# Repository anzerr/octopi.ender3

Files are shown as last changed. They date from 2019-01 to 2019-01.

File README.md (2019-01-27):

### `Intro`
Wanted to use Octoprint on a raspberry pi zero w because of its small footprint and low power usage.

Warning: The zero w will not work with a camera the CPU usage is hight negatively impacting printing results.

### `Bill of materials`
- 1 x Boost Buck Converter XL6009
- 2 x T Block Square nuts 2020 m3 or [printed version](https://www.thingiverse.com/thing:3050607)
- 1 x raspberry pi zero w
- 1 x 16gb sd card
- 2 x xt60 plug pair
- 30cm+ 14awg silicone cable
- 1 x 1k ohm resistor
- 2 x M3 Brass knurled female thread insert
- 4 x 19mm M3 screw
- 1 x 5mm M3 screw
- 1 x M3 nut
- 2 x zip ties
- Heat shrink tubing
- Hot glue or double sided tape (for the xt60 y connector)
- 1 x usb mini B to usb

### `Setup Pi`
- [Download the os](https://octoprint.org/download/)
- [Use etch flash the image onto a sd card](https://github.com/balena-io/etcher)
- Edit the octopi-wpa-supplicant.txt with your wifi credenciales.
- Connect to the octopi and finish the setup process.

### `Prints`
You can print most of these without supports. The models can be found in "./models" the source files are there with the stl. The models where made with sketchup

- 1 x [xt60_y_connector (no support)](https://github.com/anzerr/octopi.ender3/blob/master/models/stl/xt60_y_connector.stl)
- 1 x [pi_base (no support)](https://github.com/anzerr/octopi.ender3/blob/master/models/stl/pi_base.stl)
- 1 x [boost_base (no support)](https://github.com/anzerr/octopi.ender3/blob/master/models/stl/boost_base.stl)
- 1 x [case (touching buildplate support)](https://github.com/anzerr/octopi.ender3/blob/master/models/stl/case.stl)
- 2 x [spacer_pi (touching buildplate support)](https://github.com/anzerr/octopi.ender3/blob/master/models/stl/spacer_pi.stl)
- 1 x [spacer (no support)](https://github.com/anzerr/octopi.ender3/blob/master/models/stl/spacer.stl)

The only clean up needed should be drilling the holes so the screw can move freely. Add the two brass inserts to the pi_base and the parts will be ready to be assembled.

### `Wiring`
The pi pads with labels
<div style="text-align:center">
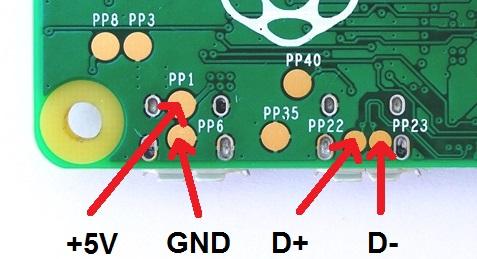
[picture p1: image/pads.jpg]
	
</div>

- Creating the xt60 Y connector.
- Use the left over male connector with the 14awg cable to create the wiring to the buck converter.
- Set the buck converter to a little under 5v.
- Wire power to the pads under the raspberry pi.
- Cut the male usb mini b cable to length and strip.
- add the 1k ohm resistor between the +5v on the pi and the red wire from the usb mini.
- wire the rest, black to gnd, green to d+ and white to d-. (on my usb mini cable I had to swap d+ and d-)

### `Images`
<div style="text-align:center">
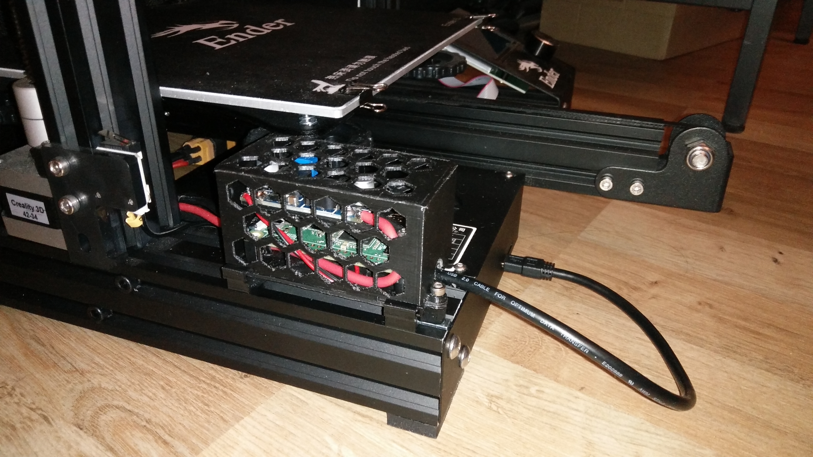
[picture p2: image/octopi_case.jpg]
	
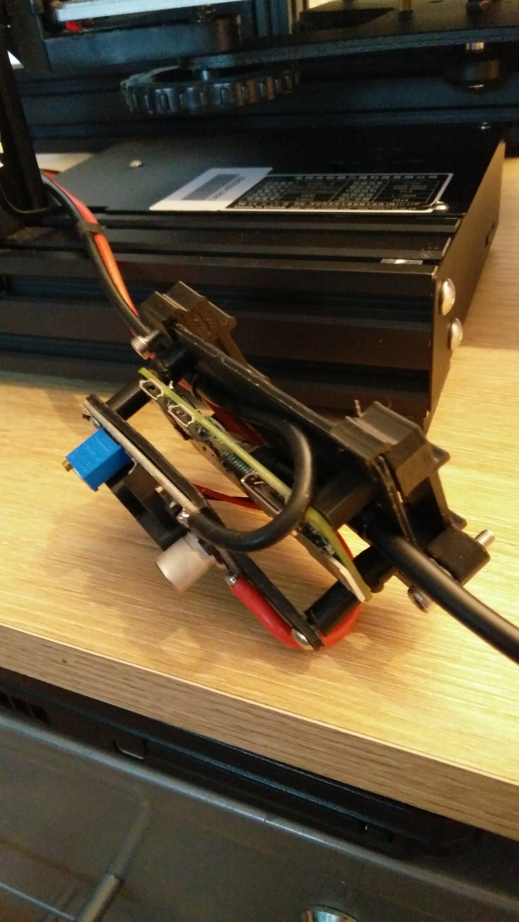
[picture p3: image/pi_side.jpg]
	
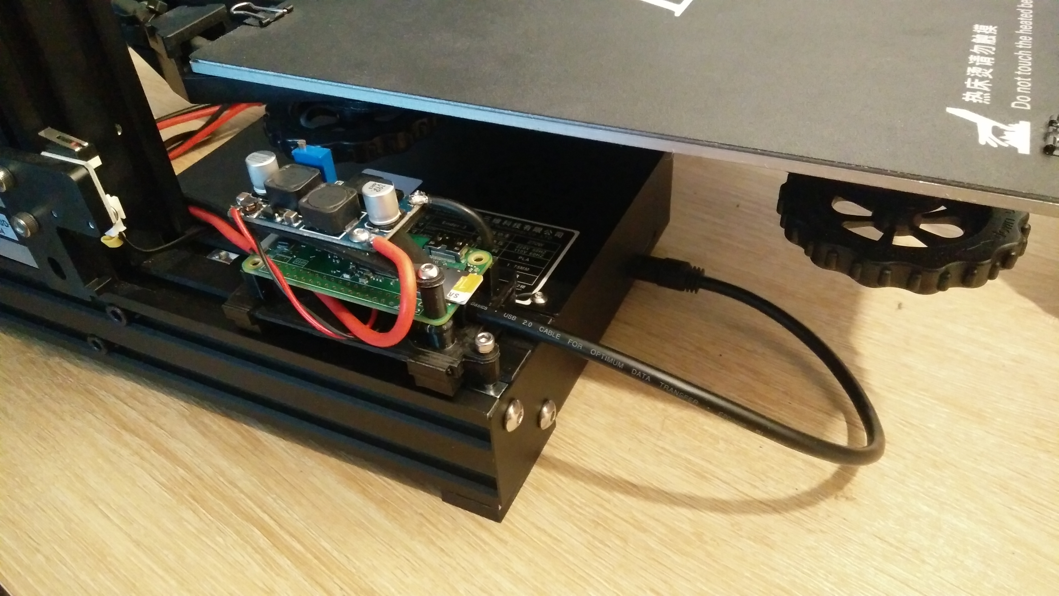
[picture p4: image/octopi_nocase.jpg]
	
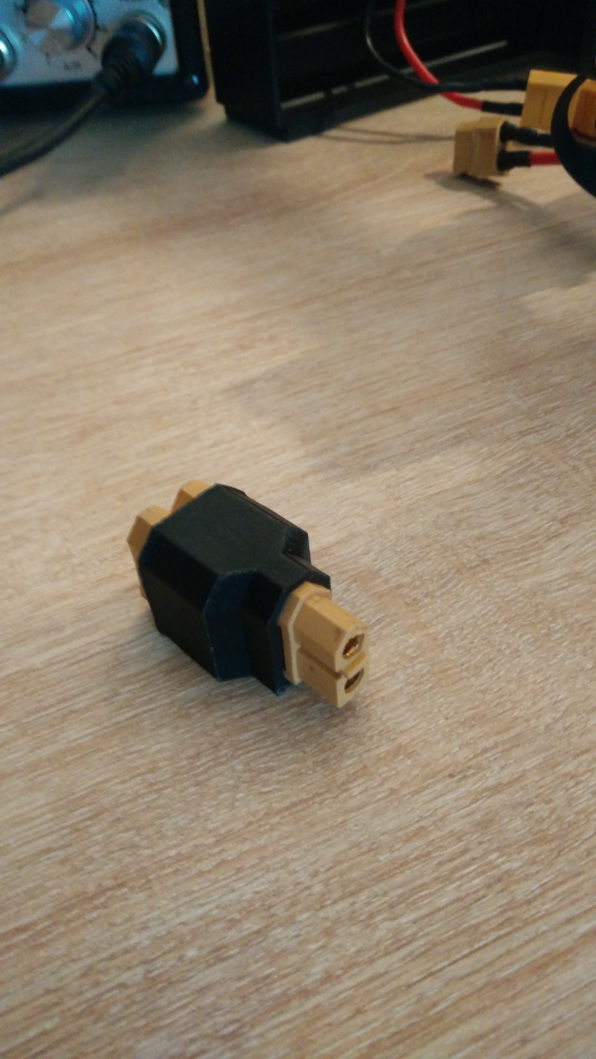
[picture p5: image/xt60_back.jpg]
	
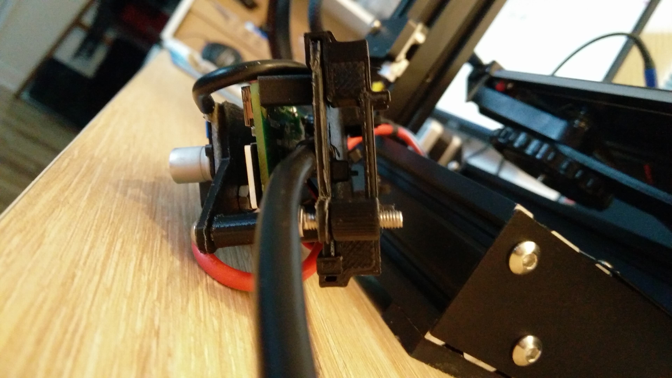
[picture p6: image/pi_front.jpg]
	
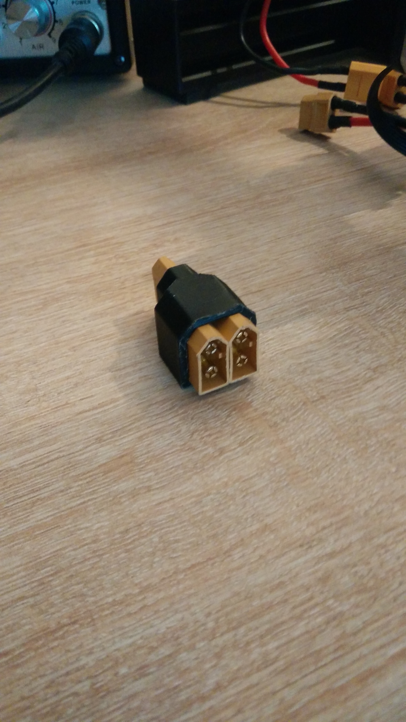
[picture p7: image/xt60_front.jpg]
	
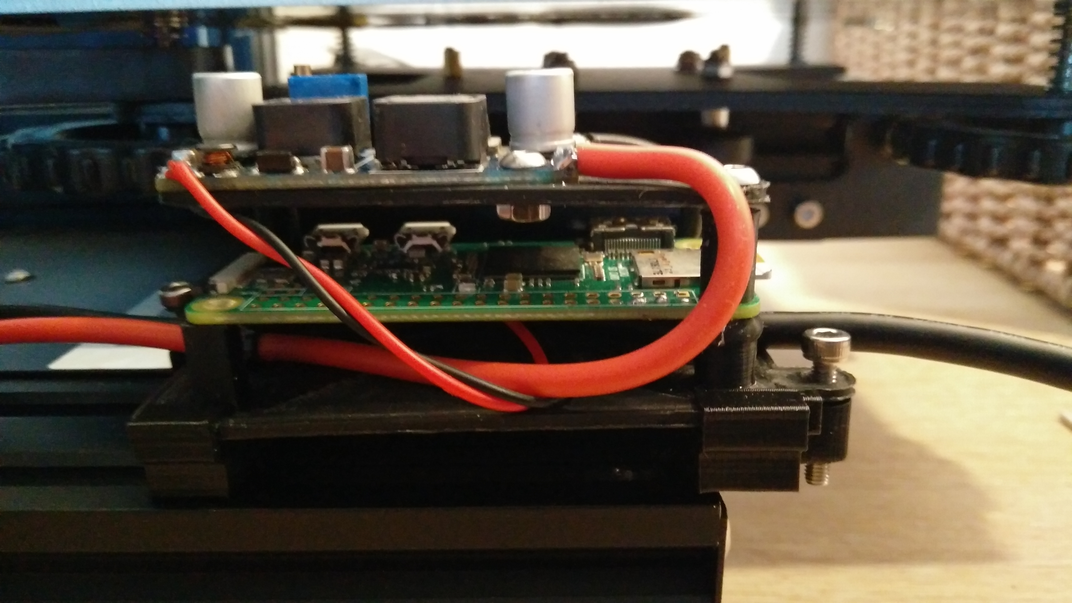
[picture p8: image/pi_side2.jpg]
	
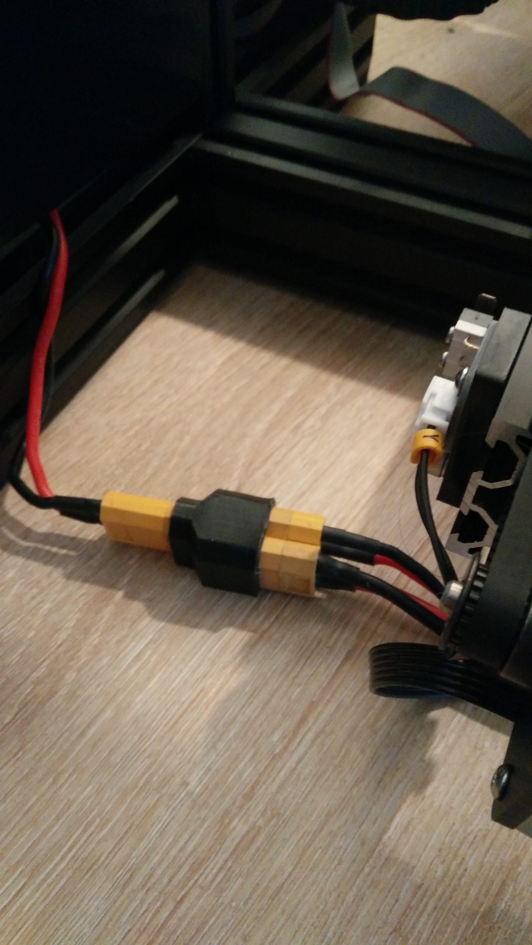
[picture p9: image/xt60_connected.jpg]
	
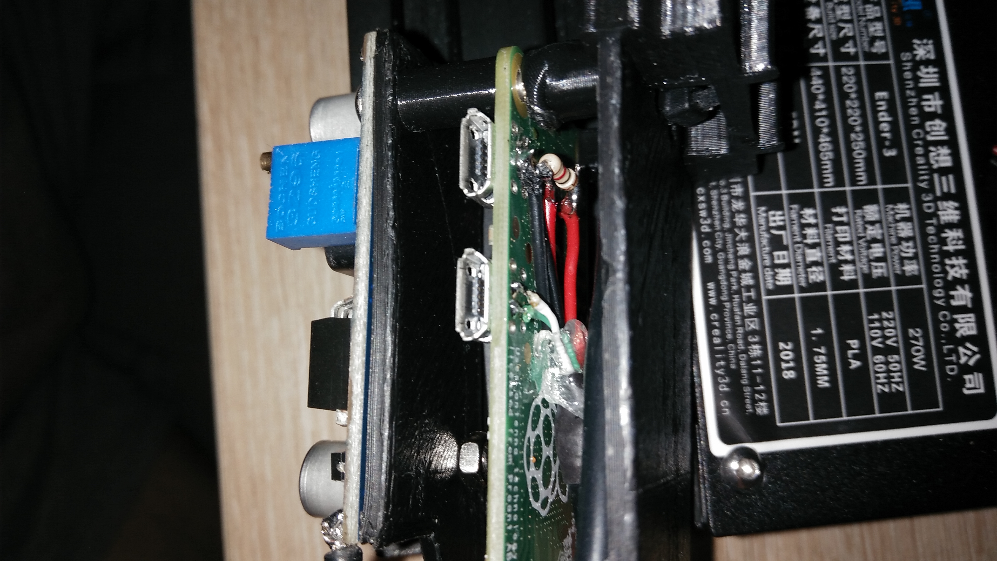
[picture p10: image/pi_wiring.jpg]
	
	<span style="height:300px;float:left;width:168.75px;background:#f3f4f4;"/>
</div>

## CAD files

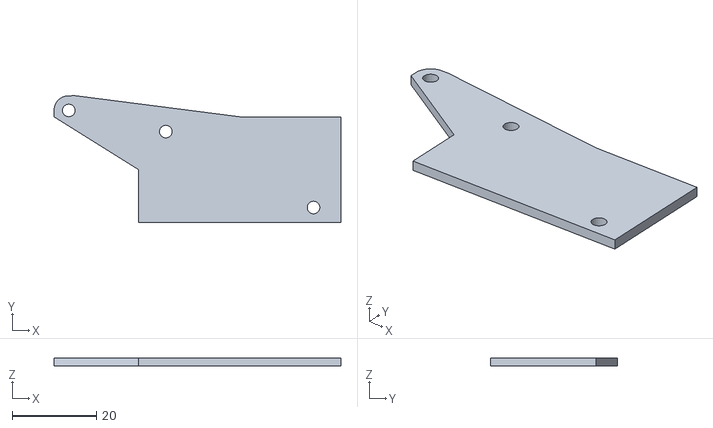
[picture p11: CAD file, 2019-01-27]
models/stl/boost_case.stl
68.0 x 30.0 x 2.00

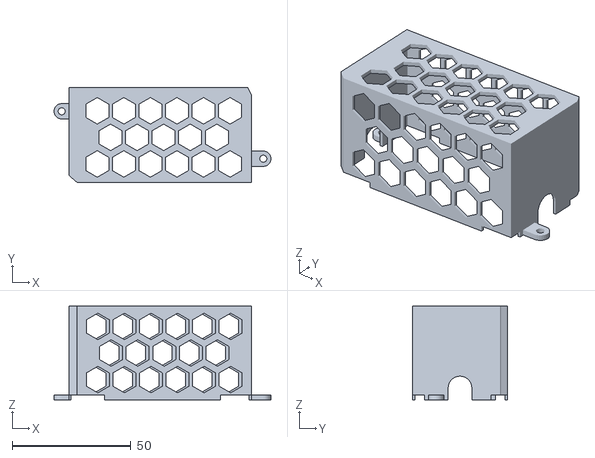
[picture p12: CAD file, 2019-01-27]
models/stl/case.stl
91.5 x 40.0 x 39.5

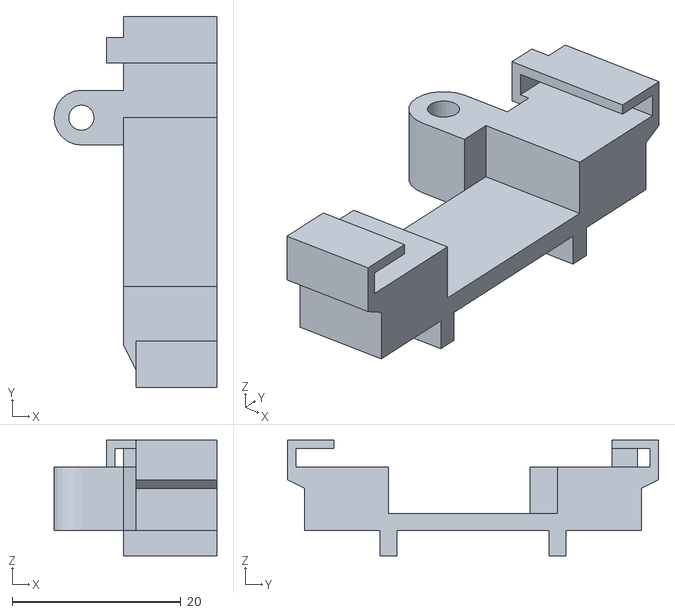
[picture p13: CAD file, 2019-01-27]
models/stl/spacer_pi.stl
19.3 x 44.0 x 13.7

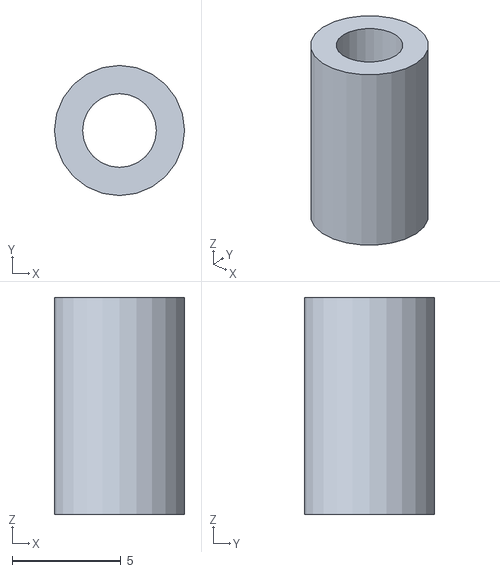
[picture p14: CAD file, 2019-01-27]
models/stl/spacer.stl
6.00 x 6.00 x 10.00

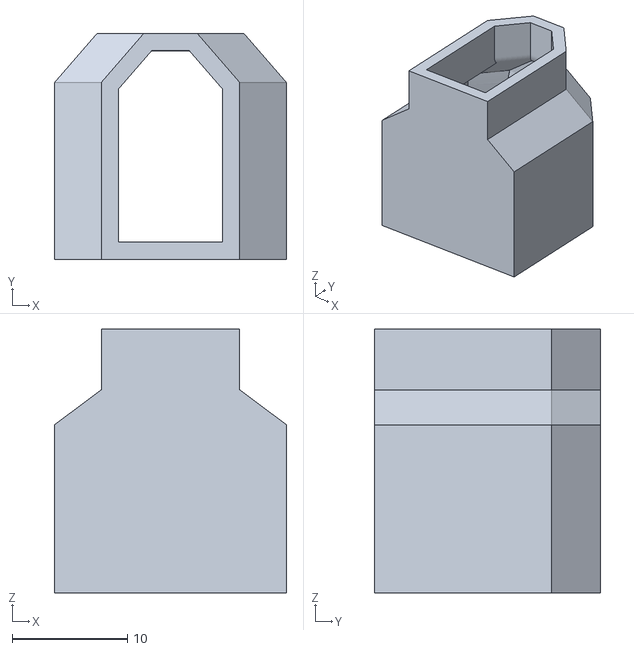
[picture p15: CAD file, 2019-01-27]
models/stl/xt60_y_connector.stl
20.1 x 19.6 x 22.9

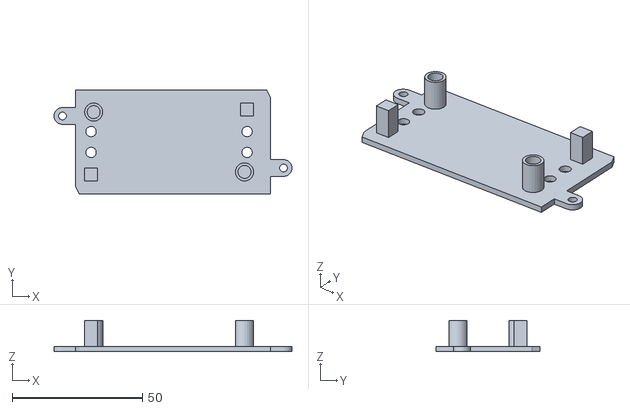
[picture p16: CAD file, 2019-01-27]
models/stl/pi_base.stl
91.5 x 40.0 x 12.0

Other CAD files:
models/source/boost_case.skp
models/source/case.skp
models/source/pi_base.skp
models/source/spacer.skp
models/source/spacer_pi.skp
models/source/xt60_y_connector.skp
